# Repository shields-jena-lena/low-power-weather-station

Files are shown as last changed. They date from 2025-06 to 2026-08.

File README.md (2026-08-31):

# low-power-weather-station
Circuity and code for a low-power weather station design used for agricultural research

Build instructions will be available in Hardware X article once published

https://doi.org/10.5281/zenodo.22212162

# File summaries:

## 3.1	Arduino_code: different code versions to upload to weather station boards
  -	weatherstation_v2.ino
    - Arduino code to run the second version of the weather station build, this version allows for sleep.
  -	weatherstation_v2_constant.ino
    - Arduino code to run the second version of the weather station build, data is taken continuously.
  -	weatherstation_v5.ino
    -	Arduino code the run the 5th version of the weather station build, this version allows sleep and includes more code for low power optimization.
  -	Weatherstation_v5_constant.ino
    -	Arduino code to run the 5th version of the weather station build, data is taken continuously.

## 3.2	CAD_files: .stl files for 3D printed sensor box
  -	Humidity box bottom 1.stl
    -	STL file to print the bottom half of the box to hold the humidity and temperature sensor.
  -	Humidity box top 1.stl
    - STL file to print the top half of the box to hold the humidity and temperature sensor.

## 3.3	KiCAD_files: Circuit design and PCB design for custom circuity for weather stations
  -	Libraries
    -	Footprints and symbols for electronic components custom designed or downloaded from digikey.
  -	weather_station_v2
    -	Complete KiCAD project files for the design and PCB layout of the 2nd version of the weather station. Includes the schematic, project file, board design, bill of materials, backups, custom_footprints, and gerber files.
  -	weather_station_v5
    -	Complete KiCAD project files for the design and PCB layout of the 5th version of the weather station. Includes the schematic, project file, board design, bill of materials, backups, and gerber files.
      
## 3.4	Matlab_code – Matlab scripts to calibrate, process, and analyze weather station data, includes sample data
  -	txtfile_to_table.m
    -	MATLAB script to convert raw data from Arduino output to a .mat table.
  -	txtfile_to_table_parpool.m
    -	MATLAB script to convert raw data from Arduino output to a .mat table, using parpool to loop through all raw data in one script.
  -	std_omidNaN.m
    -	Custom function to support other MATLAB scripts that need the standard deviation while omitting NaN values.
  -	makebigarray.m
    -	MATLAB script to take the .mat tables of each weather station and combine into a large array with data from all the stations.
  -	field_analysis.m
    -	MATLAB script to do some basic analysis on the data in the large array created by makebigarray.m.
  -	calibrate_cupanemometer.m 
    - MATLAB script to calibrate cup anemometers if you have test chamber with known wind speed and raw cup count data from the weather stations. 
  -	sample_data (Both in Matlab_code/ and in Python_code/)
    - Raw text file data from weather stations. Each data file is labeled “weather_station_b#” where # is the number of the station. Data from stations 3 through 7 is included. The station_heights.csv file reports the height of the wind measurements and temperature/humidity measurements for each station. The image field28_layout_8-29-23 shows the relative location of each station to each other. The calibration_data folder includes raw data from each weather station in a testing chamber with known wind speed.
       
## 3.5	Python_code – Python scripts to calibrate, process, and analyze wather station data, includes sample data
  -	txtfile_to_table.py
    -	Python script to convert raw data from weather station to .csv file. 
  -	txtfile_to_table_forloop.py
    -	Python script to convert raw data from weather station to .csv file, a for loop is used to loop through all weather stations in one script.
  -	makebigarray.py
    -	Python script to take the .csv tables of each weather station and combine into a large array with data from all the stations.
  -	fieldanalysis.py
    -	Python script to take the output of makebigarray.py and do some basic analysis.
  -	calibrate_cupanemometer.py
    -	Python script to calibrate cup anemometer if you have test chamber with known wind speed and raw cup count data from the weather stations. 
  -	sample_data (Both in Matlab_code/ and in Python_code/)
    -	Raw text file data from weather stations. Each data file is labeled “weather_station_b#” where # is the number of the station. Data from stations 3 through 7 is included. The station_heights.csv file reports the height of the wind measurements and temperature/humidity measurements for each station. The image field28_layout_8-29-23 shows the relative location of each station to each other. The calibration_data folder includes raw data from each weather station in a testing chamber with known wind speed.

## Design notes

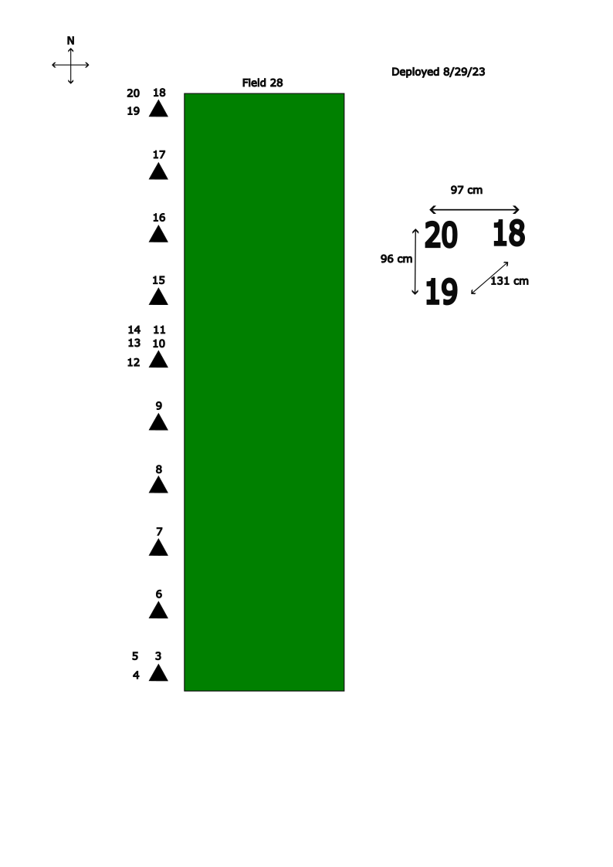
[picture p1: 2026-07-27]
Matlab_code/sample_data/field28_layout_8-29-23.png

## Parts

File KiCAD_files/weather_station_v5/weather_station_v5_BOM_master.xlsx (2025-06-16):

Designator | Component | Number | Cost per unit -USD | Total cost - | Source of materials | Material type
 |  |  |  | USD
If possible, use the same designator here as you use in the associated design file. If that’s not possible, you will need to explain the relationship between the two. | Name of Component 1 | Number of units | Cost per unit and the currency used | Total cost and the currency used | If possible, include a direct link to a webpage where the component can be purchased | Select from:
 |  |  |  |  |  | -Metal
 |  |  |  |  |  | -Semi-conductor
 |  |  |  |  |  | -Ceramic
 |  |  |  |  |  | -Polymer
 |  |  |  |  |  | -Biomaterial
 |  |  |  |  |  | -Organic
 |  |  |  |  |  | -Inorganic
 |  |  |  |  |  | -Composite
 |  |  |  |  |  | -Nanomaterial
 |  |  |  |  |  | -Semiconductor
 |  |  |  |  |  | -Non-specific
 |  |  |  |  |  | -Other
C1, C2 | 22 pF capacitor | 2 | $0.12 | $0.24 | https://www.digikey.com/en/products/detail/samsung-electro-mechanics/CL31C220JBCNNNC/3886861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 | Ceramic
C3 | 1 uF capacitor | 1 | $0.14 | $0.14 | https://www.jameco.com/webapp/wcs/stores/servlet/ProductDisplay?productId=29831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 | Electrolytic
D1 | 1N4148 diode | 1 | $0.10 | $0.10 | https://www.digikey.com/en/products/detail/diodes-incorporated/1N4148W-13-F/1933928 | Semiconductor
D2 | 1N4007 diode | 1 | $0.13 | $0.13 | https://www.digikey.com/en/products/detail/smc-diode-solutions/1N4007FL/11657817 | Semiconductor
J1, J2 | Power inputs | 2 | $0.57 | $1.14 | https://www.digikey.com/en/products/detail/on-shore-technology-inc/OSTTC022162/614558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 | Polymer
J3, J4, J5, J6, J7, J9, J10, J11, J12, J13, J15, J16 | Pins: RXD, TXD, Pin_4, Pin_5, Pin_6, A3, A2, A1, Pin_9, microsd_CD, RTC_32K, RTC_RST | 12 | ~ | ~ | ~ | Metal
J8 | 6P4C RJ11 connector | 1 | $1.63 | $1.63 | https://www.digikey.com/en/products/detail/amphenol-cs-fci/87180-064LF/1001370https://www.digikey.com/en/products/detail/amphenol-cs-fci/87180-064LF/1001370 | Polymer
J14 | RTC Socket | 1 | $0.38 | $0.38 | https://www.digikey.com/en/products/detail/w%C3%BCrth-elektronik/61300811821/17737805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 | Polymer
J17 | Micro_SD_Card_Adafruit | 1 | $7.50 | $7.50 | https://www.adafruit.com/product/254 | Other
On/Off1 | SW_SPST switch | 1 | $0.71 | $0.71 | https://www.digikey.com/en/products/detail/same-sky-formerly-cui-devices/DS04-254-2-01BK-SMT/11310848 | Polymer
Q1 | 2N7002 MOSFET | 1 | $0.10 | $0.10 | https://www.digikey.com/en/products/detail/shenzhen-slkormicro-semicon-co-ltd/2N7002/21853067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 | Semiconductor
R1 | LED BLUE DIFFUSED 1608 SMD | 1 | $0.31 | $0.31 | https://www.digikey.com/en/products/detail/rohm-semiconductor/SMLD12BN1WT86/9826162 | Semiconductor
R2 | 100 Ohm resistor | 1 | $0.10 | $0.10 | https://www.digikey.com/en/products/detail/koa-speer-electronics-inc/RK73H2BTTD1000F/10235871 | Non-specific
R3 | 20 K Ohm resistor | 1 | $0.10 | $0.10 | https://www.digikey.com/en/products/detail/yageo/RC1206FR-0720KL/728672 | Non-specific
R4, R5, R7, R8 | 10 K Ohm resistor | 4 | $0.10 | $0.40 | https://www.digikey.com/en/products/detail/yageo/RC1206FR-0710KL/728483 | Non-specific
R6 | 470 Ohm resistor | 1 | $0.10 | $0.10 | https://www.digikey.com/en/products/detail/te-connectivity-passive-product/CRGCQ1206F470R/8576408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 | Non-specific
R9 | 4.7 K Ohm resistor | 1 | $0.10 | $0.10 | https://www.digikey.com/en/products/detail/yageo/RC1206FR-074K7L/728887 | Non-specific
SW1, SW2 | push buttons | 2 | $0.21 | $0.42 | https://www.digikey.com/en/products/detail/c-k/PTS636SM50JSMTR-LFS/10071732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 | Non-specific
U1 | BS250FTA MOSFET | 1 | $0.80 | $0.80 | https://www.digikey.com/en/products/detail/diodes-incorporated/BS250FTA/58819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 | Semiconductor
U_ATMega1 | ATMega socket | 1 | $0.24 | $0.24 | https://www.digikey.com/en/products/detail/adam-tech/ICS-328-T/9832859 | Polymer
Y1 | Crystal 16 MHz | 1 | $0.20 | $0.20 | https://www.amazon.com/dp/B005MN8FPW?ref_=pe_1815430_211938580 | Inorganic
PCB board | PCB board | 1 | $2.63 | $2.63 | https://www.pcbway.com/ | Other
Battery holder | 18650 Battery Clip Holder Box Case | 1 | $0.80 | $0.80 | https://www.amazon.com/dp/B00LSG5BKO?ref_=pe_1815430_211938580 | Polymer
Battery | 18650 26V 2550mAh 7.5A | 1 | $2.27 | $2.27 | https://www.18650batterystore.com/products/eve-26v-18650-button-top-battery | Lithium-ion
Real Time Clock | DS3231 | 1 | $13.95 | $13.95 | https://www.adafruit.com/product/5188 | Other
Coin Battery | CR1220 | 1 | $0.42 | $0.42 | https://www.amazon.com/gp/product/B08GKYCD1Z/ref=ox_sc_act_title_2?smid=A2DJT6HLNLTD4S&th=1 | Lithium Manganese Dioxide
JST wire | Mini Micro SH 1.0 JST 4-pin connector plug male with 150mm cable | 2 | $0.42 | $0.84 | https://www.amazon.com/dp/B01DUC1M2O?ref_=pe_1815430_211938580 | Metal and Polymer
Temp/humidity sensor | BME280 | 1 | $14.95 | $14.95 | https://www.adafruit.com/product/2652 | Other
microSD card | 32 GB microSD | 1 | $5.20 | $5.20 | https://www.amazon.com/Lexar-Micro-microSDHC-Memory-Adapter/dp/B0CPDGYLGC?sp_csd=d2lkZ2V0TmFtZT1zcF9hdGY | Other
Microcontroller unit | ATMEGA328P-PU | 1 | $2.89 | $2.89 | https://www.digikey.com/en/products/detail/microchip-technology/ATMEGA328P-PU/1914589 | Other
wind sensors | Wind/Rain Sensor Assembly (less rain gauge) | 1 | $68.00 | $68.00 | https://www.argentdata.com/catalog/product_info.php?products_id=145 | Polymer
Housing box | LP-70F | 1 | $5.40 | $5.40 | https://www.polycase.com/lp-70f | Polymer
Housing box screws | #4-24 x .25" | 6 | $0.05 | $0.30 | https://www.polycase.com/screws-mbr-100 | Metal
Sensor box | ~ | 1 | $4.08 | $4.08 | ~ | Polymer
Sensor box bolt | #8-32 x 1/2" | 1 | $0.09 | $0.09 | https://www.homedepot.com/p/8-32-x-1-2-in-Zinc-Plated-Combo-Round-Head-Machine-Screw-100-Pack-800732/204274425 | Metal
sensor box nut | #8-32 | 1 | $0.08 | $0.08 | https://www.homedepot.com/p/Everbilt-8-32-Zinc-Plated-Machine-Screw-Nut-100-Pack-800252/204273373 | Metal
Sensor box screws | #2 x 3/8" | 4 | $0.25 | $1.00 | https://www.homedepot.com/p/Everbilt-2-x-3-8-in-Phillips-Round-Head-Brass-Wood-Screw-6-Pack-809901/204587524 | Metal
Mounting equipment - pole | U post 3ft - 7ft | 1 | $4.70-$10.28 | $4.70-$10.28 | https://www.homedepot.com/p/Everbilt-1-in-x-2-1-4-in-x-7-ft-Green-Steel-Fence-U-Post-with-Anchor-Plate-901157EB/205960885 | Metal
Mounting equipment - screw | #8-32 x 1-3/4" | 1 | $0.18 | $0.18 | https://www.homedepot.com/p/Everbilt-8-32-x-1-3-4-in-Zinc-Plated-Combo-Truss-Head-Machine-Screw-50-Pack-800992/204282656 | Metal
Mounting equipment - nut | #8-32 | 1 | $0.08 | $0.08 | https://www.homedepot.com/p/Everbilt-8-32-Zinc-Plated-Machine-Screw-Nut-100-Pack-800252/204273373 | Metal
Mounting equipment - clamp | Adjustable hose clamp | 1 | ~ | ~ | ~ | Metal

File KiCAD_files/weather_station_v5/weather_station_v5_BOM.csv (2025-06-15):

Source: | C:\Users\shiel\Documents\Github\low-power-weather-station\KiCAD_files\weather_station_lowpower\weather_station_lowpower.kicad_sch
Date: | 5/28/2025 12:34
Tool: | Eeschema 7.0.1
Generator: | C:\Program Files\KiCad\7.0\bin\scripting\plugins/bom_csv_grouped_by_value.py
Component Count: | 38
Collated Components:
Item | Qty | Reference(s) | Value | LibPart | Footprint | Datasheet | Sim.Device | Sim.Pins | Company/Manufacturer | Part # | Link | Note | Number bought | price | Price for 1 station | Note
1 | 2 | C1, C2 | 22 pF | Device:C_Small | Capacitor_SMD:C_1206_3216Metric_Pad1.33x1.80mm_HandSolder | https://weblib.samsungsem.com/mlcc/mlcc-ec-data-sheet.do?partNumber=CL05Y105KP6VPN |  |  | Digikey/Samsung Electro-Mechanics | 1276-1203-1-ND | https://www.digikey.com/en/products/detail/samsung-electro-mechanics/CL31C220JBCNNNC/3886861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 | ~ | 1 | $0.12 | $0.24 | ~
2 | 1 | C3 | 1 uF | Device:C_Polarized | Capacitor_THT:CP_Radial_D5.0mm_P2.00mm | ~ |  |  |  |  |  |  |  |  | #DIV/0!
3 | 1 | D1 | 1N4148 | Diode:1N4148 | Diode_SMD:D_SOD-123 | https://www.diodes.com/assets/Datasheets/BAV16W_1N4148W.pdf | D | 1=K 2=A | Digikey/Diodes Incorporated | 1N4148W-13FDICT-ND | https://www.digikey.com/en/products/detail/diodes-incorporated/1N4148W-13-F/1933928 | ~ | 1 | $0.10 | $0.10
4 | 1 | D2 | 1N4007 | Device:D | Diode_SMD:D_SOD-123F | https://www.smc-diodes.com/propdf/1N4001FL-1N4007FL%20N1646%20REV.C.pdf?557 | D | 1=K 2=A | Digikey/SMC Diode Solutions | 1655-1N4007FLCT-ND | https://www.digikey.com/en/products/detail/smc-diode-solutions/1N4007FL/11657817 | ~ | 1 | $0.13 | $0.13
5 | 1 | J1 | Power input | Connector:Screw_Terminal_01x02 | digikey-footprints:Term_Block_1x2_P5.08MM | ~ |  |  |  |  |  |  |  |  | #DIV/0!
6 | 1 | J2 | Ground input | :Screw_Terminal_01x02_1 | digikey-footprints:Term_Block_1x2_P5.08MM | ~ |  |  |  |  |  |  |  |  | #DIV/0!
7 | 1 | J3 | RXD | Connector:Conn_01x01_Pin | Connector_Pin:Pin_D1.0mm_L10.0mm | ~ |  |  |  |  |  |  |  |  | #DIV/0!
8 | 1 | J4 | TXD | Connector:Conn_01x01_Pin | Connector_Pin:Pin_D1.0mm_L10.0mm | ~ |  |  |  |  |  |  |  |  | #DIV/0!
9 | 1 | J5 | Pin_4 | Connector:Conn_01x01_Pin | Connector_Pin:Pin_D1.0mm_L10.0mm | ~ |  |  |  |  |  |  |  |  | #DIV/0!
10 | 1 | J6 | Pin_5 | Connector:Conn_01x01_Pin | Connector_Pin:Pin_D1.0mm_L10.0mm | ~ |  |  |  |  |  |  |  |  | #DIV/0!
11 | 1 | J7 | Pin_6 | Connector:Conn_01x01_Pin | Connector_Pin:Pin_D1.0mm_L10.0mm | ~ |  |  |  |  |  |  |  |  | #DIV/0!
12 | 1 | J8 | 6P4C | Connector:6P4C | custom_parts:RJ11_connector_jack | ~ |  |  |  |  |  |  |  |  | #DIV/0!
13 | 1 | J9 | A3 | Connector:Conn_01x01_Pin | Connector_Pin:Pin_D1.0mm_L10.0mm | ~ |  |  |  |  |  |  |  |  | #DIV/0!
14 | 1 | J10 | A2 | Connector:Conn_01x01_Pin | Connector_Pin:Pin_D1.0mm_L10.0mm | ~ |  |  |  |  |  |  |  |  | #DIV/0!
15 | 1 | J11 | A1 | Connector:Conn_01x01_Pin | Connector_Pin:Pin_D1.0mm_L10.0mm | ~ |  |  |  |  |  |  |  |  | #DIV/0!
16 | 1 | J12 | Pin_9 | Connector:Conn_01x01_Pin | Connector_Pin:Pin_D1.0mm_L10.0mm | ~ |  |  |  |  |  |  |  |  | #DIV/0!
17 | 1 | J13 | microsd_CD | Connector:Conn_01x01_Pin | Connector_Pin:Pin_D1.0mm_L10.0mm | ~ |  |  |  |  |  |  |  |  | #DIV/0!
18 | 1 | J14 | RTC | Connector:Conn_01x08_Socket | custom_parts:PinSocket_1x08_P2.54mm_Vertical_RTC | ~ |  |  |  |  |  |  |  |  | #DIV/0!
19 | 1 | J15 | RTC_32K | Connector:Conn_01x01_Pin | Connector_Pin:Pin_D1.0mm_L10.0mm | ~ |  |  |  |  |  |  |  |  | #DIV/0!
20 | 1 | J16 | RTC_RST | Connector:Conn_01x01_Pin | Connector_Pin:Pin_D1.0mm_L10.0mm | ~ |  |  |  |  |  |  |  |  | #DIV/0!
21 | 1 | J17 | Micro_SD_Card_Adafruit | Connector:Micro_SD_Card | custom_parts:adafruit_microSD_breakout_board_8-pin | ~ |  |  |  |  |  |  |  |  | #DIV/0!
23 | 1 | On/Off1 | SW_SPST | Switch:SW_SPST | custom_parts:Switch_Slide_SPST_DS04-254-2-01BK-SMT | ~ |  |  |  |  |  |  |  |  | #DIV/0!
24 | 1 | Q1 | 2N7002 | Transistor_FET:2N7002 | Package_TO_SOT_SMD:SOT-23-3 | https://www.onsemi.com/pub/Collateral/NDS7002A-D.PDF |  |  |  |  |  |  |  |  | #DIV/0!
25 | 1 | R1 | led | SMLD12BN1WT86:SMLD12BN1WT86 | led_footprints:LED_SMLD12_ROM | ~ |  |  |  |  |  |  |  |  | #DIV/0!
26 | 1 | R2 | 100 | Device:R | Resistor_SMD:R_1206_3216Metric_Pad1.30x1.75mm_HandSolder | https://www.koaspeer.com/pdfs/RK73H.pdf |  |  | Digikey/KOA Speer Electronics, Inc. | 2019-RK73H2BTTD1000FCT-ND | https://www.digikey.com/en/products/detail/koa-speer-electronics-inc/RK73H2BTTD1000F/10235871 | ~ | 1 | $0.10 | $0.10
27 | 1 | R3 | 20 K | Device:R | Resistor_SMD:R_1206_3216Metric_Pad1.30x1.75mm_HandSolder | https://www.yageo.com/upload/media/product/products/datasheet/rchip/PYu-RC_Group_51_RoHS_L_12.pdf |  |  | Digikey/YAGEO | 311-20.0KFRCT-ND | https://www.digikey.com/en/products/detail/yageo/RC1206FR-0720KL/728672 | ~ | 1 | $0.10 | $0.10
28 | 4 | R4, R5, R7, R8 | 10 K | Device:R | Resistor_SMD:R_1206_3216Metric_Pad1.30x1.75mm_HandSolder | https://www.yageo.com/upload/media/product/products/datasheet/rchip/PYu-RC_Group_51_RoHS_L_12.pdf |  |  | Digikey/YAGEO | 311-10.0KFRCT-ND | https://www.digikey.com/en/products/detail/yageo/RC1206FR-0710KL/728483 | ~ | 1 | $0.10 | $0.40
29 | 1 | R6 | 470 | Device:R | Resistor_SMD:R_1206_3216Metric_Pad1.30x1.75mm_HandSolder | https://www.te.com/usa-en/product-2-2176343-1.datasheet.pdf |  |  | Digikey/TE Connectivity Passive Product | A129806CT-ND | https://www.digikey.com/en/products/detail/te-connectivity-passive-product/CRGCQ1206F470R/8576408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 | ~ | 1 | $0.10 | $0.10
30 | 1 | R9 | 4.7 K | Device:R | Resistor_SMD:R_1206_3216Metric_Pad1.30x1.75mm_HandSolder | https://www.yageo.com/upload/media/product/products/datasheet/rchip/PYu-RC_Group_51_RoHS_L_12.pdf |  |  | Digikey/YAGEO | 311-4.70KFRCT-ND | https://www.digikey.com/en/products/detail/yageo/RC1206FR-074K7L/728887 | ~ | 1 | $0.10 | $0.10
31 | 1 | SW1 | led_push | PTS636_SM50J_SMTR_LFS:PTS636_SM50J_SMTR_LFS | switch_footprints:SW_PTS636_CNK | https://www.ckswitches.com/media/2779/pts636.pdf |  |  | Digikey/C&K | CKN12319-1-ND | https://www.digikey.com/en/products/detail/c-k/PTS636SM50JSMTR-LFS/10071732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 | ~ | 1 | $0.21 | $0.21
32 | 1 | SW2 | reset_push | PTS636_SM50J_SMTR_LFS:PTS636_SM50J_SMTR_LFS | switch_footprints:SW_PTS636_CNK | https://www.ckswitches.com/media/2779/pts636.pdf |  |  | Digikey/C&K | CKN12319-1-ND | https://www.digikey.com/en/products/detail/c-k/PTS636SM50JSMTR-LFS/10071732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 | ~ | 1 | $0.21 | $0.21
33 | 1 | U1 | BS250FTA | BS250FTA:BS250FTA | BS250FTA_footprints:SOT-23_DIO | ~ |  |  |  |  |  |  |  |  | #DIV/0!
34 | 1 | U_ATMega1 | ~ | ATMega:ATMega328 | digikey-footprints:Socket_DIP-28_7.62mm_Conn | ~ |  |  |  |  |  |  |  |  | #DIV/0!
35 | 1 | Y1 | Crystal 16 MHz | Device:Crystal_Small | Crystal:Crystal_HC18-U_Vertical | ~

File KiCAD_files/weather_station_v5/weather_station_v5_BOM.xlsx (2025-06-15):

Source: | C:\Users\shiel\Documents\Github\low-power-weather-station\KiCAD_files\weather_station_lowpower\weather_station_lowpower.kicad_sch
Date: | 2025-05-28 12:34
Tool: | Eeschema 7.0.1
Generator: | C:\Program Files\KiCad\7.0\bin\scripting\plugins/bom_csv_grouped_by_value.py
Component Count: | 38
Collated Components:
Item | Qty | Reference(s) | Value | LibPart | Footprint | Datasheet | Sim.Device | Sim.Pins | Company/Manufacturer | Part # | Link | Note | Number bought | price | Price for 1 station
1 | 2 | C1, C2 | 22 pF | Device:C_Small | Capacitor_SMD:C_1206_3216Metric_Pad1.33x1.80mm_HandSolder | https://weblib.samsungsem.com/mlcc/mlcc-ec-data-sheet.do?partNumber=CL05Y105KP6VPN | ~ | ~ | Digikey/Samsung Electro-Mechanics | 1276-1203-1-ND | https://www.digikey.com/en/products/detail/samsung-electro-mechanics/CL31C220JBCNNNC/3886861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 | ~ | 1 | $0.12 | $0.24
2 | 1 | C3 | 1 uF | Device:C_Polarized | Capacitor_THT:CP_Radial_D5.0mm_P2.00mm | https://www.jameco.com/Jameco/Products/ProdDS/29831.pdf | ~ | ~ | Jameco/James Electronics | 29831 | https://www.jameco.com/webapp/wcs/stores/servlet/ProductDisplay?productId=29831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 | ~ | 1 | $0.14 | $0.14
3 | 1 | D1 | 1N4148 | Diode:1N4148 | Diode_SMD:D_SOD-123 | https://www.diodes.com/assets/Datasheets/BAV16W_1N4148W.pdf | D | 1=K 2=A | Digikey/Diodes Incorporated | 1N4148W-13FDICT-ND | https://www.digikey.com/en/products/detail/diodes-incorporated/1N4148W-13-F/1933928 | ~ | 1 | $0.10 | $0.10
4 | 1 | D2 | 1N4007 | Device:D | Diode_SMD:D_SOD-123F | https://www.smc-diodes.com/propdf/1N4001FL-1N4007FL%20N1646%20REV.C.pdf?557 | D | 1=K 2=A | Digikey/SMC Diode Solutions | 1655-1N4007FLCT-ND | https://www.digikey.com/en/products/detail/smc-diode-solutions/1N4007FL/11657817 | ~ | 1 | $0.13 | $0.13
5 | 1 | J1 | Power input | Connector:Screw_Terminal_01x02 | digikey-footprints:Term_Block_1x2_P5.08MM | http://www.on-shore.com/wp-content/uploads/OSTTCXX2162.pdf | ~ | ~ | Digikey/On Shore Technology Inc. | ED2609-ND | https://www.digikey.com/en/products/detail/on-shore-technology-inc/OSTTC022162/614558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 | ~ | 1 | $0.57 | $0.57
6 | 1 | J2 | Ground input | :Screw_Terminal_01x02_1 | digikey-footprints:Term_Block_1x2_P5.08MM | http://www.on-shore.com/wp-content/uploads/OSTTCXX2162.pdf | ~ | ~ | Digikey/On Shore Technology Inc. | ED2609-ND | https://www.digikey.com/en/products/detail/on-shore-technology-inc/OSTTC022162/614558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 | ~ | 1 | $0.57 | $0.57
7 | 1 | J3 | RXD | Connector:Conn_01x01_Pin | Connector_Pin:Pin_D1.0mm_L10.0mm | ~ | ~ | ~ |  |  |  | Part of breadboard | 1 | $0.00 | $0.00
8 | 1 | J4 | TXD | Connector:Conn_01x01_Pin | Connector_Pin:Pin_D1.0mm_L10.0mm | ~ | ~ | ~ |  |  |  | Part of breadboard | 1 | $0.00 | $0.00
9 | 1 | J5 | Pin_4 | Connector:Conn_01x01_Pin | Connector_Pin:Pin_D1.0mm_L10.0mm | ~ | ~ | ~ |  |  |  | Part of breadboard | 1 | $0.00 | $0.00
10 | 1 | J6 | Pin_5 | Connector:Conn_01x01_Pin | Connector_Pin:Pin_D1.0mm_L10.0mm | ~ | ~ | ~ |  |  |  | Part of breadboard | 1 | $0.00 | $0.00
11 | 1 | J7 | Pin_6 | Connector:Conn_01x01_Pin | Connector_Pin:Pin_D1.0mm_L10.0mm | ~ | ~ | ~ |  |  |  | Part of breadboard | 1 | $0.00 | $0.00
12 | 1 | J8 | 6P4C | Connector:6P4C | custom_parts:RJ11_connector_jack | https://cdn.amphenol-cs.com/media/wysiwyg/files/documentation/datasheet/inputoutput/io_modularjack.pdf | ~ | ~ | Digikey/Amphenol ICC | 609-1056-ND | https://www.digikey.com/en/products/detail/amphenol-cs-fci/87180-064LF/1001370 | Same footprint but different manufacturer than I used | 1 | $1.63 | $1.63
13 | 1 | J9 | A3 | Connector:Conn_01x01_Pin | Connector_Pin:Pin_D1.0mm_L10.0mm | ~ | ~ | ~ |  |  |  | Part of breadboard | 1 | $0.00 | $0.00
14 | 1 | J10 | A2 | Connector:Conn_01x01_Pin | Connector_Pin:Pin_D1.0mm_L10.0mm | ~ | ~ | ~ |  |  |  | Part of breadboard | 1 | $0.00 | $0.00
15 | 1 | J11 | A1 | Connector:Conn_01x01_Pin | Connector_Pin:Pin_D1.0mm_L10.0mm | ~ | ~ | ~ |  |  |  | Part of breadboard | 1 | $0.00 | $0.00
16 | 1 | J12 | Pin_9 | Connector:Conn_01x01_Pin | Connector_Pin:Pin_D1.0mm_L10.0mm | ~ | ~ | ~ |  |  |  | Part of breadboard | 1 | $0.00 | $0.00
17 | 1 | J13 | microsd_CD | Connector:Conn_01x01_Pin | Connector_Pin:Pin_D1.0mm_L10.0mm | ~ | ~ | ~ |  |  |  | Part of breadboard | 1 | $0.00 | $0.00
18 | 1 | J14 | RTC | Connector:Conn_01x08_Socket | custom_parts:PinSocket_1x08_P2.54mm_Vertical_RTC | https://www.we-online.com/components/products/datasheet/61300811821.pdf | ~ | ~ | Digikey/Wurth Elektronik | 732-61300811821-ND | https://www.digikey.com/en/products/detail/w%C3%BCrth-elektronik/61300811821/17737805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 | Socket for RTC | 1 | $0.38 | $0.38
19 | 1 | J15 | RTC_32K | Connector:Conn_01x01_Pin | Connector_Pin:Pin_D1.0mm_L10.0mm | ~ | ~ | ~ |  |  |  | Part of breadboard | 1 | $0.00 | $0.00
20 | 1 | J16 | RTC_RST | Connector:Conn_01x01_Pin | Connector_Pin:Pin_D1.0mm_L10.0mm | ~ | ~ | ~ |  |  |  | Part of breadboard | 1 | $0.00 | $0.00
21 | 1 | J17 | Micro_SD_Card_Adafruit | Connector:Micro_SD_Card | custom_parts:adafruit_microSD_breakout_board_8-pin | ~ | ~ | ~ | Adafruit | 254 | https://www.adafruit.com/product/254 | ~ | 1 | $7.50 | $7.50
23 | 1 | On/Off1 | SW_SPST | Switch:SW_SPST | custom_parts:Switch_Slide_SPST_DS04-254-2-01BK-SMT | https://www.cuidevices.com/product/resource/ds04-254-smt.pdf | ~ | ~ | Digikey/Same Sky | 2223-DS04-254-2-01BK-SMT-ND | https://www.digikey.com/en/products/detail/same-sky-formerly-cui-devices/DS04-254-2-01BK-SMT/11310848 | ~ | 1 | $0.71 | $0.71
24 | 1 | Q1 | 2N7002 | Transistor_FET:2N7002 | Package_TO_SOT_SMD:SOT-23-3 | https://mm.digikey.com/Volume0/opasdata/d220001/medias/docus/6778/5399_2N7002%20SOT-23.PDF | ~ | ~ | Digikey/Shenzhen Slkormicro Semicon Co., Ltd. | 5399-2N7002CT-ND | https://www.digikey.com/en/products/detail/shenzhen-slkormicro-semicon-co-ltd/2N7002/21853067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 | ~ | 1 | $0.10 | $0.10
25 | 1 | R1 | led | SMLD12BN1WT86:SMLD12BN1WT86 | led_footprints:LED_SMLD12_ROM | https://www.rohm.com/datasheet?p=SMLD12BN1W&dist=Digi-key&media=referral&campaign=Digi-key | ~ | ~ | Digikey/Rohm Semiconductor | SMLD12BN1WT86CT-ND | https://www.digikey.com/en/products/detail/rohm-semiconductor/SMLD12BN1WT86/9826162 | ~ | 1 | $0.31 | $0.31
26 | 1 | R2 | 100 | Device:R | Resistor_SMD:R_1206_3216Metric_Pad1.30x1.75mm_HandSolder | https://www.koaspeer.com/pdfs/RK73H.pdf | ~ | ~ | Digikey/KOA Speer Electronics, Inc. | 2019-RK73H2BTTD1000FCT-ND | https://www.digikey.com/en/products/detail/koa-speer-electronics-inc/RK73H2BTTD1000F/10235871 | ~ | 1 | $0.10 | $0.10
27 | 1 | R3 | 20 K | Device:R | Resistor_SMD:R_1206_3216Metric_Pad1.30x1.75mm_HandSolder | https://www.yageo.com/upload/media/product/products/datasheet/rchip/PYu-RC_Group_51_RoHS_L_12.pdf | ~ | ~ | Digikey/YAGEO | 311-20.0KFRCT-ND | https://www.digikey.com/en/products/detail/yageo/RC1206FR-0720KL/728672 | ~ | 1 | $0.10 | $0.10
28 | 4 | R4, R5, R7, R8 | 10 K | Device:R | Resistor_SMD:R_1206_3216Metric_Pad1.30x1.75mm_HandSolder | https://www.yageo.com/upload/media/product/products/datasheet/rchip/PYu-RC_Group_51_RoHS_L_12.pdf | ~ | ~ | Digikey/YAGEO | 311-10.0KFRCT-ND | https://www.digikey.com/en/products/detail/yageo/RC1206FR-0710KL/728483 | ~ | 1 | $0.10 | $0.40
29 | 1 | R6 | 470 | Device:R | Resistor_SMD:R_1206_3216Metric_Pad1.30x1.75mm_HandSolder | https://www.te.com/usa-en/product-2-2176343-1.datasheet.pdf | ~ | ~ | Digikey/TE Connectivity Passive Product | A129806CT-ND | https://www.digikey.com/en/products/detail/te-connectivity-passive-product/CRGCQ1206F470R/8576408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 | ~ | 1 | $0.10 | $0.10
30 | 1 | R9 | 4.7 K | Device:R | Resistor_SMD:R_1206_3216Metric_Pad1.30x1.75mm_HandSolder | https://www.yageo.com/upload/media/product/products/datasheet/rchip/PYu-RC_Group_51_RoHS_L_12.pdf | ~ | ~ | Digikey/YAGEO | 311-4.70KFRCT-ND | https://www.digikey.com/en/products/detail/yageo/RC1206FR-074K7L/728887 | ~ | 1 | $0.10 | $0.10
31 | 1 | SW1 | led_push | PTS636_SM50J_SMTR_LFS:PTS636_SM50J_SMTR_LFS | switch_footprints:SW_PTS636_CNK | https://www.ckswitches.com/media/2779/pts636.pdf | ~ | ~ | Digikey/C&K | CKN12319-1-ND | https://www.digikey.com/en/products/detail/c-k/PTS636SM50JSMTR-LFS/10071732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 | ~ | 1 | $0.21 | $0.21
32 | 1 | SW2 | reset_push | PTS636_SM50J_SMTR_LFS:PTS636_SM50J_SMTR_LFS | switch_footprints:SW_PTS636_CNK | https://www.ckswitches.com/media/2779/pts636.pdf | ~ | ~ | Digikey/C&K | CKN12319-1-ND | https://www.digikey.com/en/products/detail/c-k/PTS636SM50JSMTR-LFS/10071732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 | ~ | 1 | $0.21 | $0.21
33 | 1 | U1 | BS250FTA | BS250FTA:BS250FTA | BS250FTA_footprints:SOT-23_DIO | https://www.diodes.com/assets/Datasheets/BS250F.pdf | ~ | ~ | Digikey/Diodes Incorporated | BS250FCT-ND | https://www.digikey.com/en/products/detail/diodes-incorporated/BS250FTA/58819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 | ~ | 1 | $0.80 | $0.80
34 | 1 | U_ATMega1 | ~ | ATMega:ATMega328 | digikey-footprints:Socket_DIP-28_7.62mm_Conn | https://app.adam-tech.com/products/download/data_sheet/199582/ics-3xx-t-data-sheet.pdf | ~ | ~ | Digikey/Adam Tech | 2057-ICS-328-T-ND | https://www.digikey.com/en/products/detail/adam-tech/ICS-328-T/9832859 | Socket for MCU | 1 | $0.24 | $0.24
35 | 1 | Y1 | Crystal 16 MHz | Device:Crystal_Small | Crystal:Crystal_HC18-U_Vertical | ~ | ~ | ~ | Amazon/uxcell | B07Y7GFVGX | https://www.amazon.com/dp/B005MN8FPW?ref_=pe_1815430_211938580 | ~ | 50 | $9.99 | $0.20

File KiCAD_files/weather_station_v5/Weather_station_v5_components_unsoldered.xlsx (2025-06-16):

Type: | Non soldered components of weather station
Date: | 2025-05-28 15:00
Component Count: | 29
Item | Qty | Type | Value | Datasheet | Company/Manufacturer | Part # | Link | Note | Number bought | price | Price for 1 station | Note
36 | 1 | Battery holder | 18650 Battery Clip Holder Box Case | ~ | Amazon/HiLetgo | B00LSG5BKO | https://www.amazon.com/dp/B00LSG5BKO?ref_=pe_1815430_211938580 | ~ | 10 | $7.99 | $0.80
37 | 1 | Battery | 18650 26V 2550mAh 7.5A | https://cdn.shopify.com/s/files/1/0481/9678/0183/files/EVE_ICR18650-26V_RD-EVE_ICR18650-26V-S118-LF-A.pdf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 | 18650 Battery Store/EVE | ICR18650-26V | https://www.18650batterystore.com/products/eve-26v-18650-button-top-battery | ~ | 50 | $113.47 | $2.27 | Includes shipping and tax, with deal
38 | 1 | Real Time Clock | DS3231 | ~ | Adafruit | 5188 | https://www.adafruit.com/product/5188 | ~ | 1 | $13.95 | $13.95
39 | 1 | Coin Battery | CR1220 | ~ | Amazon/SKOANBE | B08GKYCD1Z | https://www.amazon.com/gp/product/B08GKYCD1Z/ref=ox_sc_act_title_2?smid=A2DJT6HLNLTD4S&th=1 | ~ | 24 | $9.99 | $0.42
40 | 2 | JST wire | Mini Micro SH 1.0 JST 4-pin connector plug male with 150mm cable | ~ | Amazon/Daier | B01DUC1M2O | https://www.amazon.com/dp/B01DUC1M2O?ref_=pe_1815430_211938580 | Two soldered together for a longer cable | 20 | $8.39 | $0.84
41 | 1 | Temp/humidity sensor | BME280 | ~ | Adafruit | 2652 | https://www.adafruit.com/product/2652 | ~ | 1 | $14.95 | $14.95
42 | 1 | microSD card | 32 GB microSD | ~ | Amazon/Lexar | LMSESXX032G-B5AAA | https://www.amazon.com/Lexar-Micro-microSDHC-Memory-Adapter/dp/B0CPDGYLGC?sp_csd=d2lkZ2V0TmFtZT1zcF9hdGY | ~ | 5 | $25.99 | $5.20
43 | 1 | Microcontroller unit | ATMEGA328P-PU | https://ww1.microchip.com/downloads/en/DeviceDoc/ATmega48A-PA-88A-PA-168A-PA-328-P-DS-DS40002061B.pdf | Digikey/Microchip Technology | ATMEGA328P-PU-ND | https://www.digikey.com/en/products/detail/microchip-technology/ATMEGA328P-PU/1914589 | ~ | 1 | $2.89 | $2.89
44 | 1 | wind sensors | Wind/Rain Sensor Assembly (less rain gauge) | https://www.argentdata.com/files/80422_datasheet.pdf | Argent data | 80422 | https://www.argentdata.com/catalog/product_info.php?products_id=145 | ~ | 50 | $2295.42 | $45.91 | Includes shipping and tax
45 | 1 | Housing box | LP-70F | ~ | Polycase | LP-70FMB | https://www.polycase.com/lp-70f | ~ | 1 | $5.40 | $5.40
46 | 6 | Housing box screws | #4-24 x .25" | ~ | Polycase | SCREWS-MBR-100 | https://www.polycase.com/screws-mbr-100 | ~ | 100 | $4.22 | $0.25
47 | 1 | Sensor box | ~ | ~ | ~ | ~ | ~ | 3D-printed (CAD files located:..\CAD_files) | 50 | $204.00 | $4.08 | Estimate
48 | 1 | Sensor box bolt | #8-32 x 1/2" | ~ | Home Depot/Everbilt | 800732 | https://www.homedepot.com/p/8-32-x-1-2-in-Zinc-Plated-Combo-Round-Head-Machine-Screw-100-Pack-800732/204274425 | ~ | 100 | $8.97 | $0.09
49 | 1 | sensor box nut | #8-32 | ~ | Home Depot/Everbilt | 800252 | https://www.homedepot.com/p/Everbilt-8-32-Zinc-Plated-Machine-Screw-Nut-100-Pack-800252/204273373 | ~ | 100 | $7.67 | $0.08
50 | 4 | Sensor box screws | #2 x 3/8" | ~ | Home Depot/Everbilt | 809901 | https://www.homedepot.com/p/Everbilt-2-x-3-8-in-Phillips-Round-Head-Brass-Wood-Screw-6-Pack-809901/204587524 | ~ | 6 | $1.47 | $0.98
51 | 1 | PCB board | ~ | ~ | PCBWay | ~ | https://www.pcbway.com/ | Manufacturer for PCB board | 10 | $26.26 | $2.63 | Includes shipping and tax, with deal
52 | 1 | U post | 3ft - 7ft | ~ | Home Depot/Everbilt | 901157EB | https://www.homedepot.com/p/Everbilt-1-in-x-2-1-4-in-x-7-ft-Green-Steel-Fence-U-Post-with-Anchor-Plate-901157EB/205960885 | ~ | 1 | $10.28 | $10.28
53 | 1 | Mounting post nut | #8-32 | ~ | Home Depot/Everbilt | 800252 | https://www.homedepot.com/p/Everbilt-8-32-Zinc-Plated-Machine-Screw-Nut-100-Pack-800252/204273373 | ~ | 100 | $7.67 | $0.08
54 | 1 | Mounting post screw | #8-32 x 1-3/4" | ~ | Home Depot/Everbilt | 800992 | https://www.homedepot.com/p/Everbilt-8-32-x-1-3-4-in-Zinc-Plated-Combo-Truss-Head-Machine-Screw-50-Pack-800992/204282656 | ~ | 50 | $8.98 | $0.18
55 | 1 | Mounting post clamp | Adjustable hose clamp | ~ | Argent data | ~ | ~ | Came with argent data order | ~ | ~ | ~
 |  |  |  |  |  |  |  |  |  | total | $111.26

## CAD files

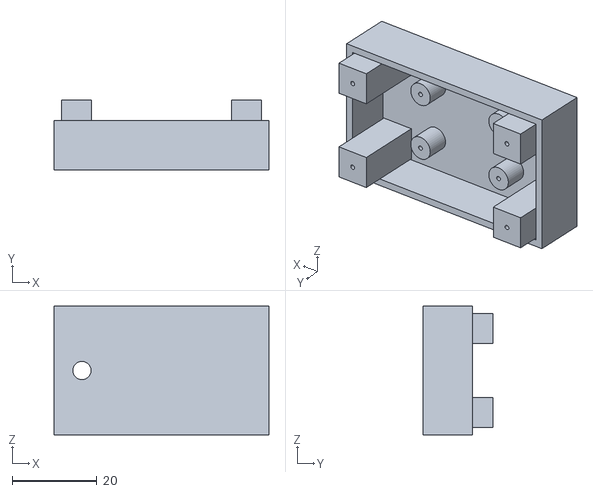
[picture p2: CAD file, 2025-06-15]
CAD_files/Humidity box bottom 1.STL
50.8 x 16.5 x 30.5

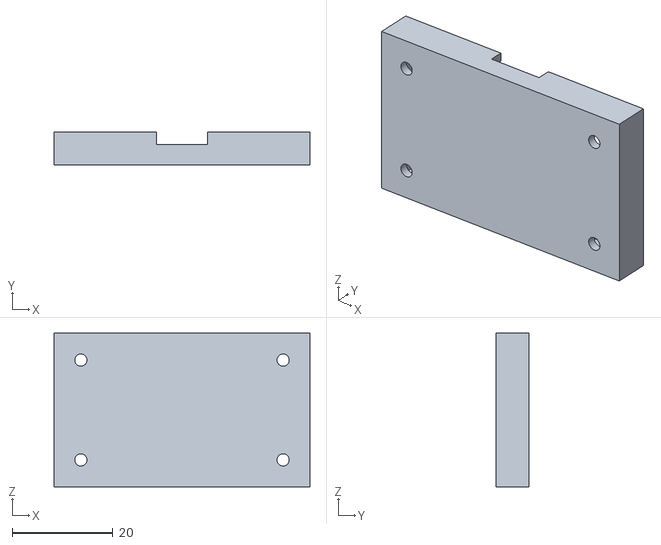
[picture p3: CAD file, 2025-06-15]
CAD_files/Humidity box top 1.STL
50.8 x 6.60 x 30.5

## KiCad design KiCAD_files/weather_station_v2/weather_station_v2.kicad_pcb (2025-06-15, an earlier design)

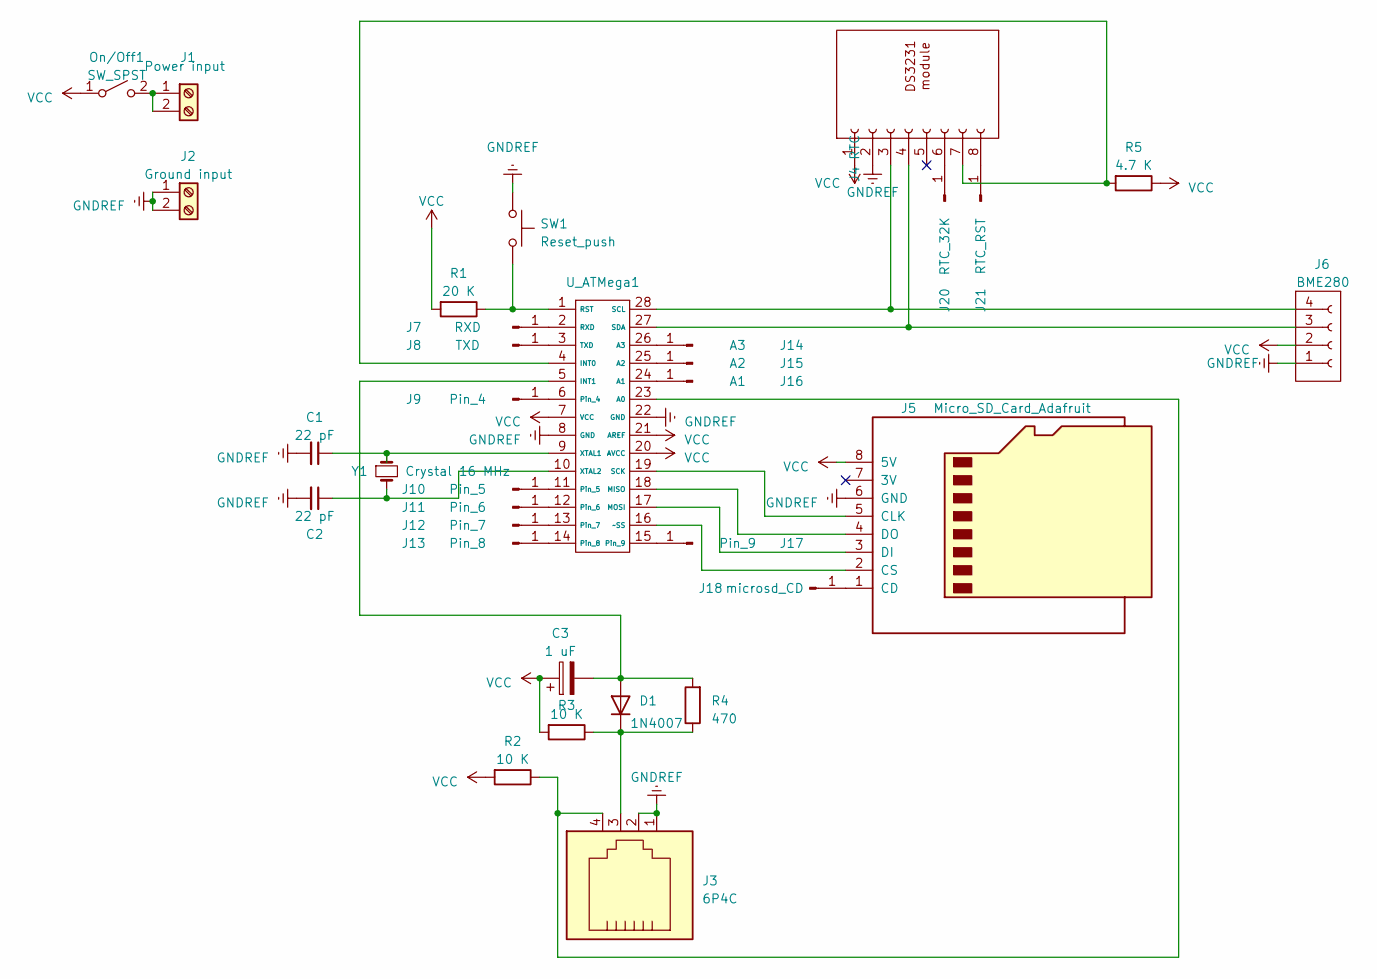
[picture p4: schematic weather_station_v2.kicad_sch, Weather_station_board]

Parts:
C1, C2: 22 pF; C_1206_3216Metric_Pad1.33x1.80mm_HandSolder
C3: 1 uF; C_Elec_4x5.4
D1: 1N4007; D_SOD-123F
J1: Power input; Term_Block_1x2_P5.08MM
J2: Ground input; Term_Block_1x2_P5.08MM
J3: 6P4C; RJ11_connector_jack
J4: RTC; PinSocket_1x08_P2.54mm_Vertical_RTC
J5: Micro_SD_Card_Adafruit; adafruit_microSD_breakout_board_8-pin
J6: BME280; JST-SH
J7: RXD; Pin_D1.0mm_L10.0mm
J8: TXD; Pin_D1.0mm_L10.0mm
J9: Pin_4; Pin_D1.0mm_L10.0mm
J10: Pin_5; Pin_D1.0mm_L10.0mm
J11: Pin_6; Pin_D1.0mm_L10.0mm
J12: Pin_7; Pin_D1.0mm_L10.0mm
J13: Pin_8; Pin_D1.0mm_L10.0mm
J14: A3; Pin_D1.0mm_L10.0mm
J15: A2; Pin_D1.0mm_L10.0mm
J16: A1; Pin_D1.0mm_L10.0mm
J17: Pin_9; Pin_D1.0mm_L10.0mm
J18: microsd_CD; Pin_D1.0mm_L10.0mm
J20: RTC_32K; Pin_D1.0mm_L10.0mm
J21: RTC_RST; Pin_D1.0mm_L10.0mm
On/Off1: SW_SPST; Switch_Slide_SPST_DS04-254-2-01BK-SMT
R1: 20 K; R_1206_3216Metric_Pad1.30x1.75mm_HandSolder
R2, R3: 10 K; R_1206_3216Metric_Pad1.30x1.75mm_HandSolder
R4: 470; R_1206_3216Metric_Pad1.30x1.75mm_HandSolder
R5: 4.7 K; R_1206_3216Metric_Pad1.30x1.75mm_HandSolder
SW1: Reset_push; SW_Tactile_SPST_NO_Straight_CK_PTS636Sx25SMTRLFS
U_ATMega1: Socket_DIP-28_7.62mm_Conn
Y1: Crystal 16 MHz; Crystal_HC18-U_Vertical

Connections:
GNDREF: C1.2, C2.2, J2.1, J2.2, J3.1, J3.2, J4.2 (GND), J5.6 (GND), J6.1, SW1.1, U_ATMega1.8 (GND), U_ATMega1.22 (GND)
unnamed: C3.2, D1.2 (A), R4.2, U_ATMega1.5 (INT1)
unnamed: D1.1 (K), J3.3, R3.1, R4.1
unnamed: J1.1, J1.2, On/Off1.2 (B)
unnamed: J4.3 (SCL), J6.4, U_ATMega1.28 (SCL)
unnamed: J4.4 (SDA), J6.3, U_ATMega1.27 (SDA)
unnamed: J4.7 (SQW), R5.2, U_ATMega1.4 (INT0)
unnamed: J5.5 (CLK), U_ATMega1.19 (SCK)
unnamed: J5.2 (CS), U_ATMega1.16 (~SS)
unnamed: J5.3 (DI), U_ATMega1.17 (MOSI)
unnamed: J5.4 (DO), U_ATMega1.18 (MISO)
unnamed: J7.1, U_ATMega1.2 (RXD)
unnamed: J8.1, U_ATMega1.3 (TXD)
unnamed: J9.1, U_ATMega1.6 (Pin_4)
unnamed: J10.1, U_ATMega1.11 (Pin_5)
unnamed: J11.1, U_ATMega1.12 (Pin_6)
unnamed: J12.1, U_ATMega1.13 (Pin_7)
unnamed: J13.1, U_ATMega1.14 (Pin_8)
unnamed: J14.1, U_ATMega1.26 (A3)
unnamed: J15.1, U_ATMega1.25 (A2)
unnamed: J16.1, U_ATMega1.24 (A1)
unnamed: J17.1, U_ATMega1.15 (Pin_9)
unnamed: J5.1 (CD), J18.1
unnamed: J4.6 (32K), J20.1
unnamed: J4.8 (RST), J21.1
unnamed: J3.4, R2.1, U_ATMega1.23 (A0)
unnamed: R1.1, SW1.2, U_ATMega1.1 (RST)
unnamed: C1.1, U_ATMega1.9 (XTAL1), Y1.1
unnamed: C2.1, U_ATMega1.10 (XTAL2), Y1.2
VCC: C3.1, J4.1 (Vin), J5.8 (5V), J6.2, On/Off1.1 (A), R1.2, R2.2, R3.2, R5.1, U_ATMega1.7 (VCC), U_ATMega1.20 (AVCC), U_ATMega1.21 (AREF)

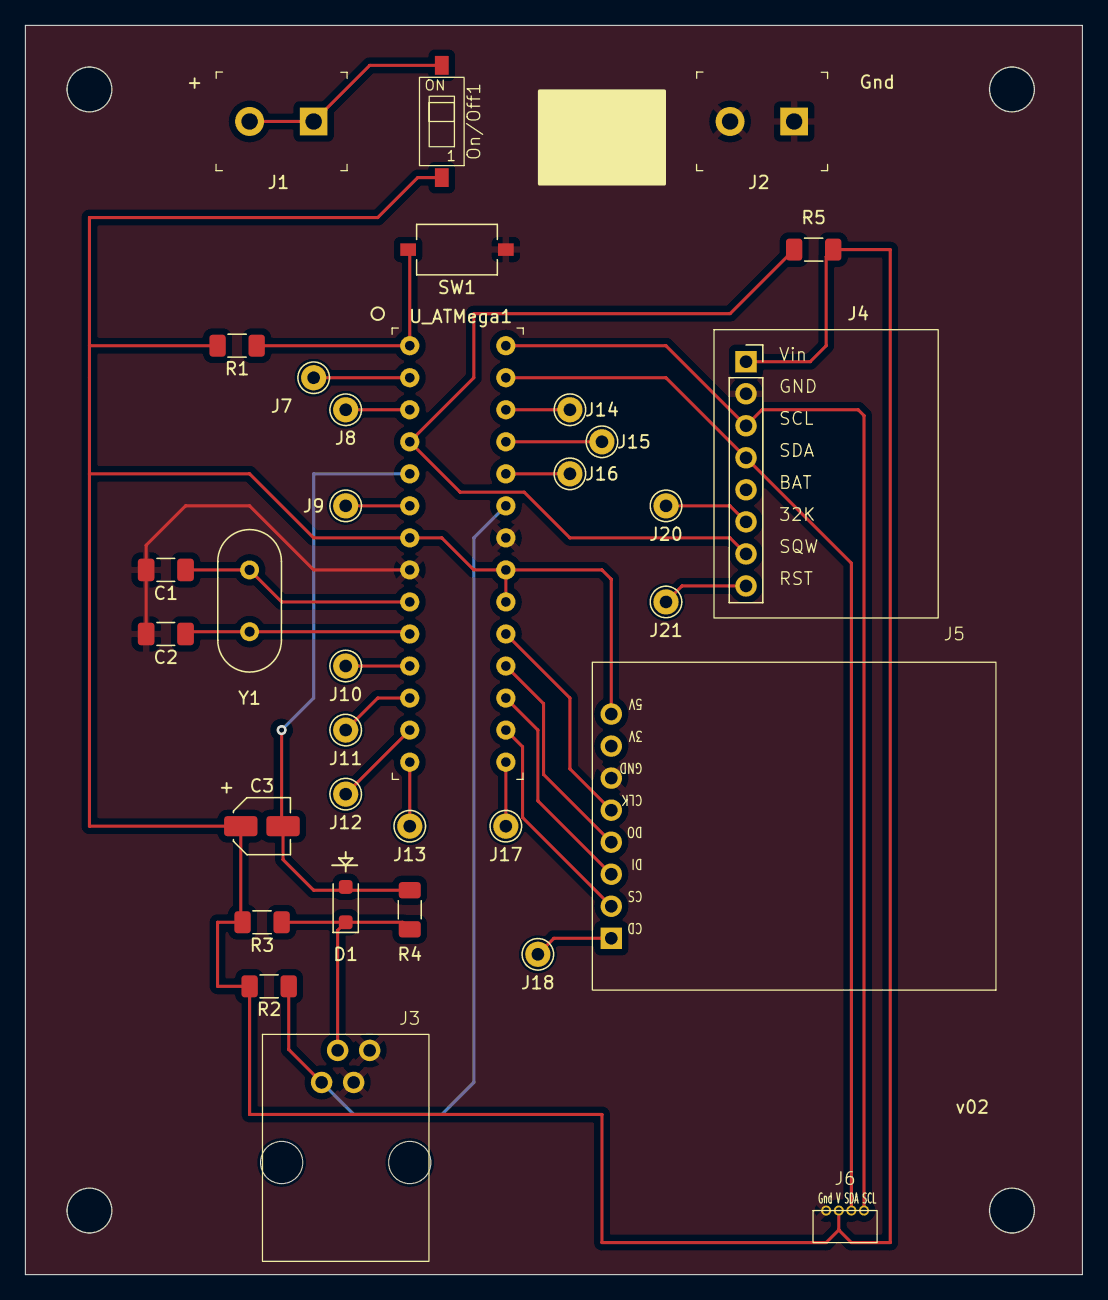
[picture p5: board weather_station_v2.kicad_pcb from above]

Board: 2 copper layers, 83.8 x 99.1 mm, 33 parts (0 on the bottom side), 30 nets.

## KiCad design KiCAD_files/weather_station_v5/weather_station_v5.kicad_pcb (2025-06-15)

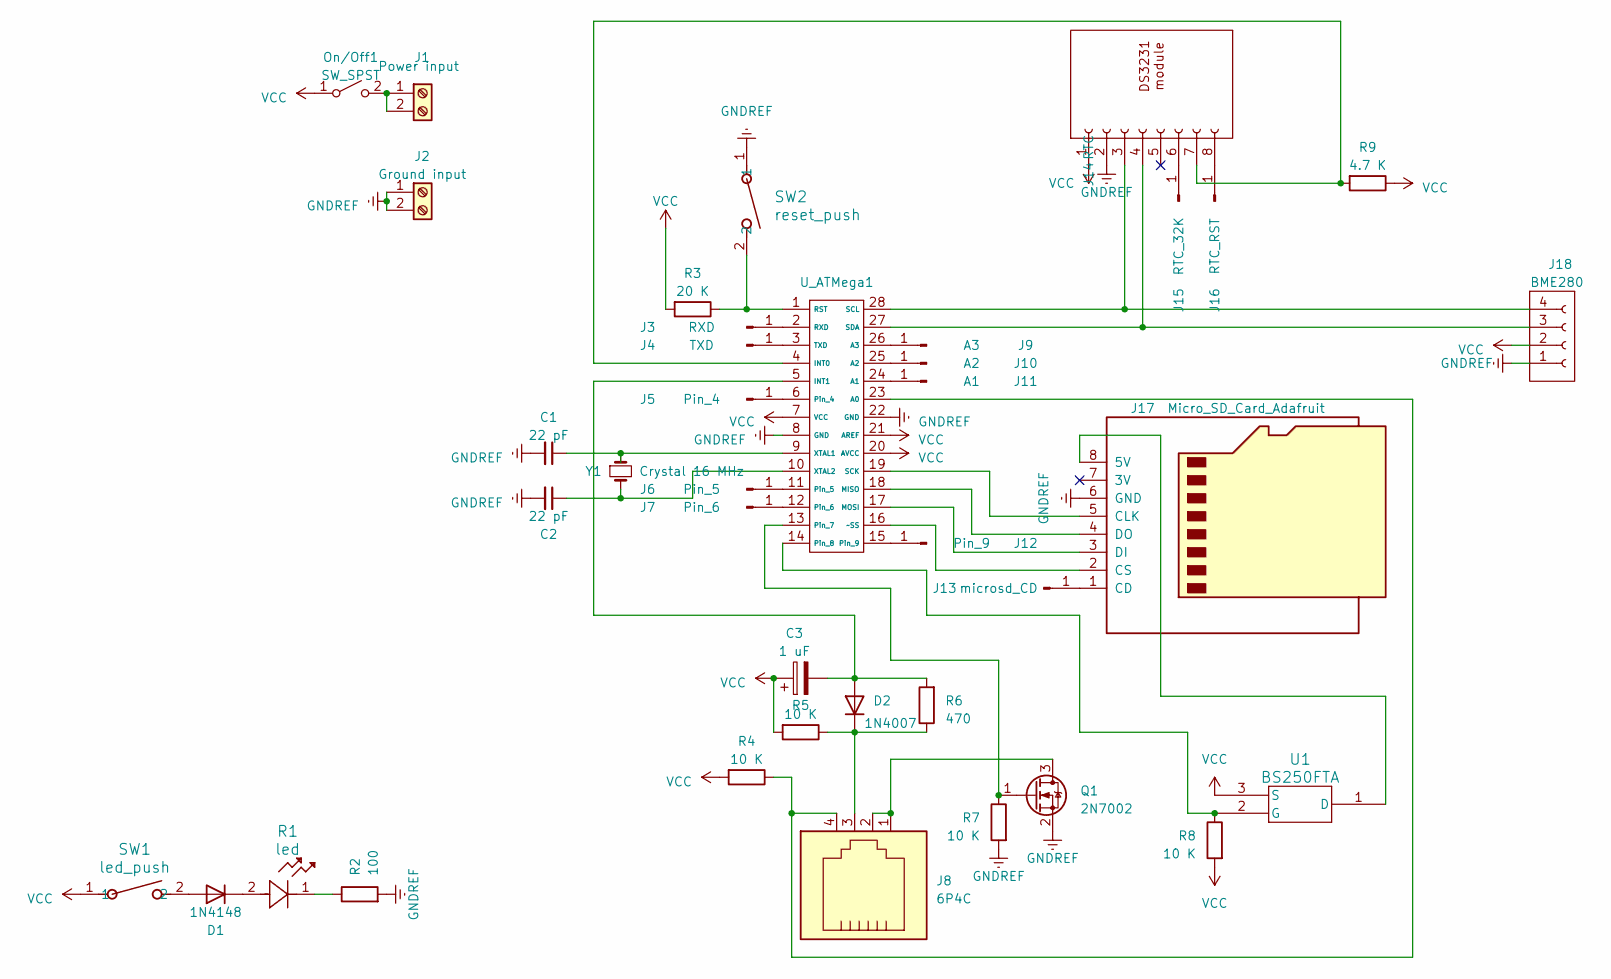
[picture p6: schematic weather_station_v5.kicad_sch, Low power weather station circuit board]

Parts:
C1, C2: 22 pF; C_1206_3216Metric_Pad1.33x1.80mm_HandSolder
C3: 1 uF; CP_Radial_D5.0mm_P2.00mm
D1: 1N4148; D_SOD-123
D2: 1N4007; D_SOD-123F
J1: Power input; Term_Block_1x2_P5.08MM
J2: Ground input; Term_Block_1x2_P5.08MM
J3: RXD; Pin_D1.0mm_L10.0mm
J4: TXD; Pin_D1.0mm_L10.0mm
J5: Pin_4; Pin_D1.0mm_L10.0mm
J6: Pin_5; Pin_D1.0mm_L10.0mm
J7: Pin_6; Pin_D1.0mm_L10.0mm
J8: 6P4C; RJ11_connector_jack
J9: A3; Pin_D1.0mm_L10.0mm
J10: A2; Pin_D1.0mm_L10.0mm
J11: A1; Pin_D1.0mm_L10.0mm
J12: Pin_9; Pin_D1.0mm_L10.0mm
J13: microsd_CD; Pin_D1.0mm_L10.0mm
J14: RTC; PinSocket_1x08_P2.54mm_Vertical_RTC
J15: RTC_32K; Pin_D1.0mm_L10.0mm
J16: RTC_RST; Pin_D1.0mm_L10.0mm
J17: Micro_SD_Card_Adafruit; adafruit_microSD_breakout_board_8-pin
J18: BME280; JST-SH
On/Off1: SW_SPST; Switch_Slide_SPST_DS04-254-2-01BK-SMT
Q1: 2N7002; SOT-23-3
R1: led; LED_SMLD12_ROM
R2: 100; R_1206_3216Metric_Pad1.30x1.75mm_HandSolder
R3: 20 K; R_1206_3216Metric_Pad1.30x1.75mm_HandSolder
R4, R5, R7, R8: 10 K; R_1206_3216Metric_Pad1.30x1.75mm_HandSolder
R6: 470; R_1206_3216Metric_Pad1.30x1.75mm_HandSolder
R9: 4.7 K; R_1206_3216Metric_Pad1.30x1.75mm_HandSolder
SW1: led_push; SW_PTS636_CNK
SW2: reset_push; SW_PTS636_CNK
U1: BS250FTA; SOT-23_DIO
U_ATMega1: Socket_DIP-28_7.62mm_Conn
Y1: Crystal 16 MHz; Crystal_HC18-U_Vertical

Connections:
GNDREF: C1.2, C2.2, J2.1, J2.2, J14.2 (GND), J17.6 (GND), J18.1, Q1.2 (S), R2.2, R7.2, SW2.1, U_ATMega1.8 (GND), U_ATMega1.22 (GND)
unnamed: D1.2 (A), SW1.2
unnamed: D1.1 (K), R1.2
unnamed: C3.2, D2.2 (A), R6.2, U_ATMega1.5 (INT1)
unnamed: D2.1 (K), J8.3, R5.1, R6.1
unnamed: J1.1, J1.2, On/Off1.2 (B)
unnamed: J3.1, U_ATMega1.2 (RXD)
unnamed: J4.1, U_ATMega1.3 (TXD)
unnamed: J5.1, U_ATMega1.6 (Pin_4)
unnamed: J6.1, U_ATMega1.11 (Pin_5)
unnamed: J7.1, U_ATMega1.12 (Pin_6)
unnamed: J9.1, U_ATMega1.26 (A3)
unnamed: J10.1, U_ATMega1.25 (A2)
unnamed: J11.1, U_ATMega1.24 (A1)
unnamed: J12.1, U_ATMega1.15 (Pin_9)
unnamed: J13.1, J17.1 (CD)
unnamed: J14.6 (32K), J15.1
unnamed: J14.8 (RST), J16.1
unnamed: J14.3 (SCL), J18.4, U_ATMega1.28 (SCL)
unnamed: J14.4 (SDA), J18.3, U_ATMega1.27 (SDA)
unnamed: J14.7 (SQW), R9.2, U_ATMega1.4 (INT0)
unnamed: J17.8 (5V), U1.1 (D)
unnamed: J17.5 (CLK), U_ATMega1.19 (SCK)
unnamed: J17.2 (CS), U_ATMega1.16 (~SS)
unnamed: J17.3 (DI), U_ATMega1.17 (MOSI)
unnamed: J17.4 (DO), U_ATMega1.18 (MISO)
unnamed: J8.1, J8.2, Q1.3 (D)
unnamed: Q1.1 (G), R7.1, U_ATMega1.13 (Pin_7)
unnamed: R1.1, R2.1
unnamed: R8.1, U1.2 (G), U_ATMega1.14 (Pin_8)
unnamed: J8.4, R4.1, U_ATMega1.23 (A0)
unnamed: R3.1, SW2.2, U_ATMega1.1 (RST)
unnamed: C1.1, U_ATMega1.9 (XTAL1), Y1.1
unnamed: C2.1, U_ATMega1.10 (XTAL2), Y1.2
VCC: C3.1, J14.1 (Vin), J18.2, On/Off1.1 (A), R3.2, R4.2, R5.2, R8.2, R9.1, SW1.1, U1.3 (S), U_ATMega1.7 (VCC), U_ATMega1.20 (AVCC), U_ATMega1.21 (AREF)

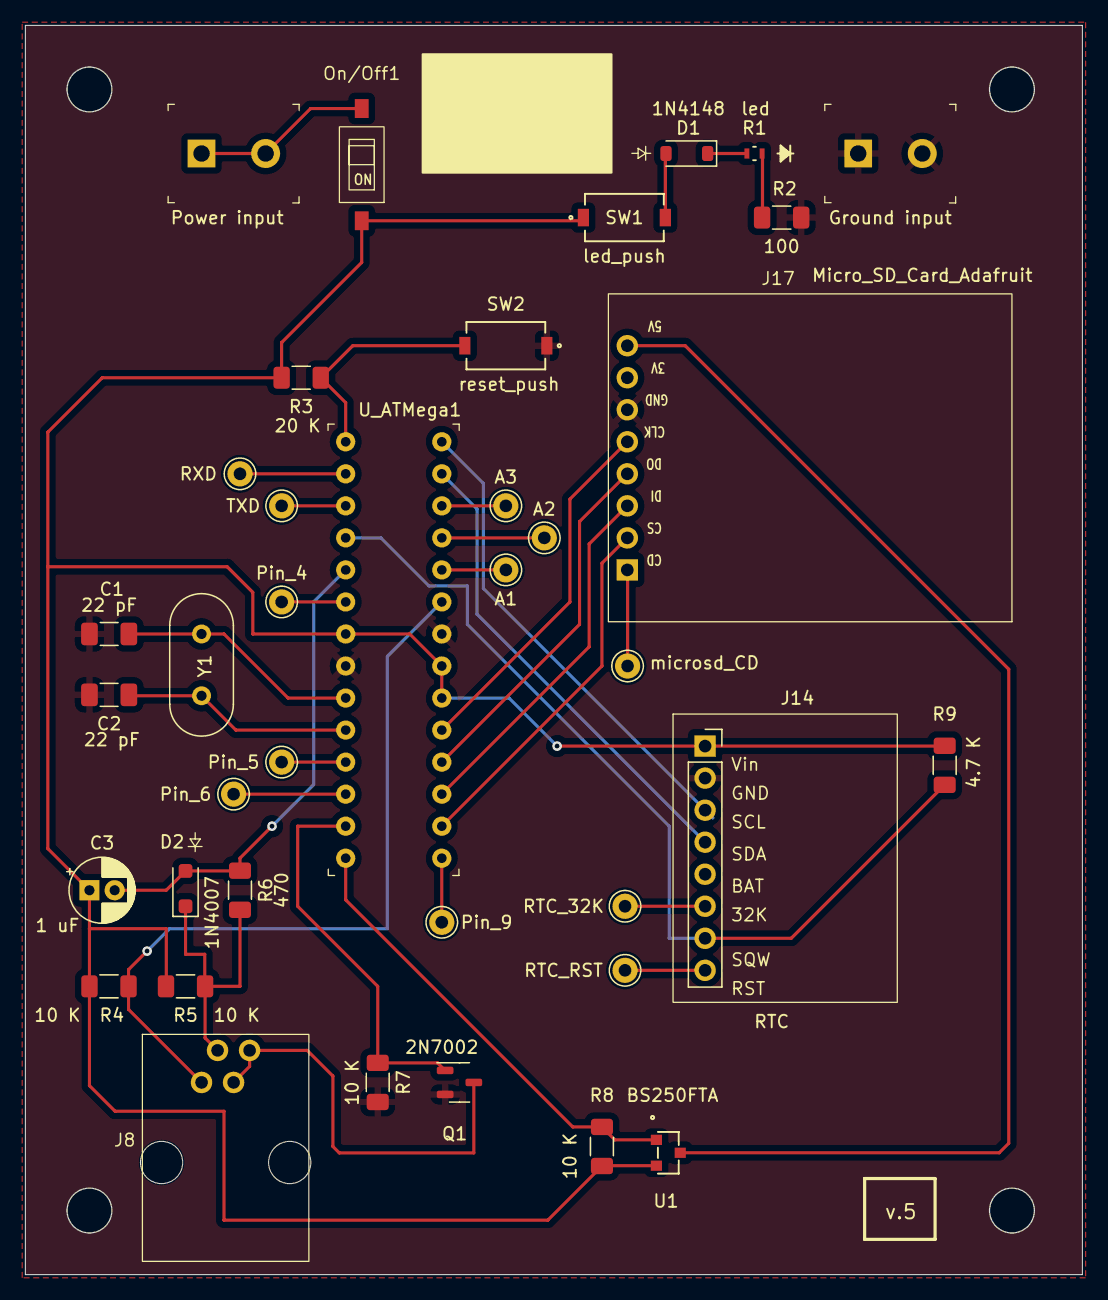
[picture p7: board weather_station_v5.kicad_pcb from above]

Board: 2 copper layers, 83.8 x 99.1 mm, 38 parts (0 on the bottom side), 35 nets.

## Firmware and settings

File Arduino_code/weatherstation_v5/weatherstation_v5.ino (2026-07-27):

// Weather station code for v5
// Code to modify for each station: filename
// Code to modify in general: delay_time, num_data, setAlarm1/alarm_type
// Using digital pins: 2 (interrupt, clock), 3 (interrupt, cup), 7 (wind sensors), 8 (SD card)
// analog pins: 0(wind vane)
// SPI for SD card (Use pins 10-13)
// I2C for real time clock (rtc) and humidity/temperature sensor (bme280)
// Written by: Jena Shields
// Last updated: 7/22/26
// Software: Arduino IDE 2.0.1

#include <RTClib.h> //Needed for the real time clock (RTC)
#include <SPI.h> //Needed for SPI connection, used for SD card
#include <Wire.h> //Needed for I2C connection, used for the RTC and BME280
#include <Adafruit_Sensor.h> //Needed for the ada fruit sensors (BME280)
#include <Adafruit_BME280.h> //Needed for the temp/humidity sensor (BME280)
#include <SdFat.h> //Needed for running the SD card storage
#include <avr/sleep.h> //Needed for putting into sleep mode

//Change these variables as needed:
const char filename[] = "weatherstation_b5_1.txt";
long delaytime = 1000; //wait between individual measurements
int num_data = 10; //number of measurements taken before sleeping
int alarm_type = 2; //Alarm type 1 = every hour, type 2 = every minute, if you want something else must change code below

//Set up SD card and data management for code
File myFile;
// These values depend on the type of arduino used 
const int chipSelect = 10; //connection to chip select (cs) on the sd card, 53 for mega, 10 for uno
const int MOSIPin = 11; //MOSI connection between SD and arduino
const int MISOPin = 12; //MISO connection between SD and arduino
const int SCKPin = 13; //Serial clock connection between SD and arduino
SdFat SD; //Initialize the SD card 
char buf [10]; //set buffer size for SD card
char data[150]; //measured data in each measurement stored here

//Set up BME sensor
#define SEALEVELPRESSURE_HPA (1013.25) //Needed for pressure measurements of BME280, sea level pressure
Adafruit_BME280 bme; //initialize the BME280

//Set up RTC
RTC_DS3231 rtc; //initialze the real time clock
char daysOfTheWeek[7][12] = {"Sunday", "Monday", "Tuesday", "Wednesday", "Thursday", "Friday", "Saturday"}; //set the days of the week 

//Set up wind wane
#define wind_vane 0 //set pin reading in the voltage for the wind vane
float wind_vane_volt; //initialize variable to store the measurement from wind vane

//Set up cup anemometer
#define counter_interrupt  3 //interrupt pin for cup anemometer counter
volatile int cup_count = 0; //This integer will count up everytime the interrupt is triggered

//interrupt pin for the RTC alarm to wake up system
#define clock_interrupt  2

void setup() {
  Serial.begin(9600); //Set baud rate for serial communication

  //set up SPI pins
  pinMode(chipSelect, OUTPUT);
  pinMode(MOSIPin, OUTPUT);
  pinMode(MISOPin, INPUT);
  pinMode(SCKPin, OUTPUT);
  digitalWrite(13,LOW);

 //turn unused pins low power 
 pinMode(0, INPUT_PULLUP);
 pinMode(1, INPUT_PULLUP);
 pinMode(4, INPUT_PULLUP);
 pinMode(5, INPUT_PULLUP);
 pinMode(6, INPUT_PULLUP);
 pinMode(9, INPUT_PULLUP);
 pinMode(A1, INPUT_PULLUP);
 pinMode(A2, INPUT_PULLUP);
 pinMode(A3, INPUT_PULLUP);

 //turn on SD card and wind sensors, activates MOSFET to allow power to these components 
  pinMode(7, OUTPUT); //wind sensors, 
  pinMode(8, OUTPUT); //SD card
  digitalWrite(7, HIGH);
  digitalWrite(8, LOW);

  //Start the rtc
   if (! rtc.begin()) {
    Serial.println("Could not find rtc? Check wiring");
    while (1) delay(10);
  }
  // start the bme and set to forced measurements and turn off pressure
   if (! bme.begin()) {
    Serial.println("Could not find bme? Check wiring");
    while (1) delay(10);
  }
    bme.setSampling(Adafruit_BME280::MODE_FORCED,
                Adafruit_BME280::SAMPLING_X4,   // temperature
                Adafruit_BME280::SAMPLING_NONE, // pressure
                Adafruit_BME280::SAMPLING_X16,   // humidity
                Adafruit_BME280::FILTER_OFF );
                // can also set the wait time

  // start SD card
  if (!SD.begin(chipSelect)) {
    Serial.println("initialization failed!");
    while (1) delay(10);
  }
  
  //Set up the interrupt pins
  pinMode(clock_interrupt, INPUT_PULLUP);
  pinMode(counter_interrupt, INPUT_PULLUP);
  
  // set up cup counter to count everytime an interrupt is read
  interrupts();
  attachInterrupt(digitalPinToInterrupt(counter_interrupt), cup_Counter, RISING);
  
  //Set up alarm clock
  rtc.disable32K();
  rtc.clearAlarm(1);
  rtc.clearAlarm(2);
  rtc.writeSqwPinMode(DS3231_OFF);
  rtc.disableAlarm(2);

  //CHANGE THIS TO CHANGE SLEEP TIME
  if (alarm_type == 1){
    rtc.setAlarm1(DateTime(0,0,0,0,0,0), DS3231_A1_Minute); //every hour on the hour alarm
  }
  else if (alarm_type == 2){
    rtc.setAlarm1(DateTime(0,0,0,0,0,0), DS3231_A1_Second); // every minute alarm
  }
  else {
    rtc.setAlarm1(DateTime(0,0,0,0,0,0), DS3231_A1_Second); // every minute alarm
  }
}

void loop() {
  cup_count = 0; //restart cup count at beginning of measurement burst
  myFile = SD.open(filename, FILE_WRITE); // open the file in the SD card
 
 // take num_data amount of measurements 
  for (int i = 0; i < num_data; i++) {
      memset(data, 0, sizeof data); //clear the variable data
      DateTime now = rtc.now(); //get current time
      long start = millis(); //log starting time of measurement
      bme.takeForcedMeasurement(); //initialize measurements 
      
      //time stamp
      char datetime[] = "YY/MM/DD,hh:mm:ss,"; //format to save date time info
      strcpy(data, now.toString(datetime)); //get date time in string format
       
      //rtc temp;
      dtostrf(rtc.getTemperature(), 5, 2, buf); //measure temperature with rtc
      strcat(data, buf); strcat(data, ","); //save measurement as string
    
      //bme temp;
      dtostrf(bme.readTemperature(), 5, 2, buf); //measure temperature with bme
      strcat(data, buf); strcat(data, ","); //save measurement as string

      //bme humidity;
      dtostrf(bme.readHumidity(), 5, 2, buf); //measure humidity with bme
      strcat(data, buf); strcat(data, ","); //save measurement as string
    
      //wind vane
      wind_vane_volt = analogRead(wind_vane); //read wind vane voltage measurement
      dtostrf(wind_vane_volt, 4, 2, buf); //get voltage measurement as string
      strcat(data, buf); strcat(data, ","); //save measurement as string

      //cup_counts
      int counts = cup_count; //cup_counts has been growing, record current number
      dtostrf(counts, 1, 0, buf); //convert number to string
      strcat(data, buf); strcat(data, ";"); //save measurement of cup rotations

      myFile.write(data); //write data to SD card
      //Serial.println(data);
      delay(delaytime - millis() + start); //wait until next time to take data
  }
  myFile.close(); //close the file

   // go to sleep
   bme.setSampling(Adafruit_BME280::MODE_SLEEP); //put bme in sleep mode
   delay(100); //delay to allow bme to sleep

   byte adcsra_save = ADCSRA; //Save state of Analog to digital converty
   ADCSRA = 0; //turn of Analog to digital converter
   SD.end(); //"close" SD Card
   SPI.end(); // end SPI transmission

   digitalWrite(7, LOW); // turn off wind sensors
   digitalWrite(8, HIGH); // turn off sd card

   Going_To_Sleep();//turn on alarm clock and alarm interrupt, turn off arduino, alarm set
    
   //awake again
   ADCSRA = adcsra_save; // turn on ADC, set to setting before sleep
   digitalWrite(7, HIGH); // turn on wind sensors
   digitalWrite(8, LOW); // turn on sd card 
   SPI.begin(); // restart SD Card 
   if (!SD.begin(chipSelect)) {
    Serial.println("initialization failed!");
    while (1) delay(10);
   }

   attachInterrupt(digitalPinToInterrupt(counter_interrupt), cup_Counter, RISING); //turn on cup anemometer counter
   //turn on bme 
   bme.setSampling(Adafruit_BME280::MODE_FORCED,
            Adafruit_BME280::SAMPLING_X4,   // temperature
            Adafruit_BME280::SAMPLING_NONE, // pressure
            Adafruit_BME280::SAMPLING_X16,   // humidity
            Adafruit_BME280::FILTER_OFF );
                // can also set the wait time
}

//How the interrupt works to count cup anemometer
void cup_Counter(){
  cup_count++;
}

void Going_To_Sleep(){
  sleep_enable();
  //rtc.setAlarm1(rtc.now() + TimeSpan(0,1,0,0),DS3231_A1_Hour); // this mode triggers the alarm in an hour when minutes +seconds match)
  rtc.clearAlarm(1);
  detachInterrupt(digitalPinToInterrupt(counter_interrupt)); //turn off cup counter interrupt
  attachInterrupt(0, onAlarm, LOW); //turn on clock alarm interrupt
  set_sleep_mode(SLEEP_MODE_PWR_DOWN); //set sleep mode
  delay(1000);
  sleep_cpu(); //sleep mode for arduino
}

void onAlarm(){ 
  sleep_disable();  //wake up arduino
  detachInterrupt(0);  //turn off clock alarm 
}

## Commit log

2025-05-27 Upload and comment weatherstation_field_lowpower.ino
    Uploaded the current version of the low power weather station code. Commented out the code for readability.
2025-06-15 KiCad and arduino files added, matlab edited
    Added kicad files of schematic and PCB board design to folder. Edited matlab scripts, added arduino scripts. Need to keep working on all.
    [Humidity box bottom 1.STL, Humidity box top 1.STL, Weather_station_lowpower_components_unsoldered.xlsx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]
2025-06-16 Upload old materials, comment codes
    Add kicad files for v2 build, add/comment on arduino codes for both versions, add a continuous version for v5. Finish commenting matlab codes and add calibration data for the 5 stations.
    [Weather_station_lowpower_components_unsoldered.xlsx, Weather_station_v5_components_unsoldered.xlsx, weather_station.csv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]
2026-07-22 Updates from last time opened
    [ws_3.xlsx]
2026-07-27 Codes updated and sample data compiled
    [calibrations.csv, station_heights.csv, ws_3.xlsx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]
2026-07-27 Remove all analyzed data, keep raw only
    [calibrations.csv, ws_3.xlsx, ws_4.xlsx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]
